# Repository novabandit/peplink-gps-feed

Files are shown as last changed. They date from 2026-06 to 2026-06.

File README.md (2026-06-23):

# Restoring GPS to a Peplink B One 5G (and similar) over raw NMEA

A cheap, reliable way to give a Peplink router a live GPS position again by feeding it raw NMEA 0183 over the LAN. A small ESP32-with-Ethernet board reads a real GPS receiver and pushes the stream to the router. Total parts cost is roughly $40, less if you already own a USB-to-serial adapter.

> **Licenses:** firmware in `firmware/` is MIT (`LICENSE`). The 3D models in `enclosure/`, the documentation in `docs/`, and this README are CC BY-NC-SA 4.0 (`LICENSE-hardware`). The enclosure is a remix of upstream NonCommercial work, so the NonCommercial terms apply to the models and docs; the firmware is original and stays MIT.

## The problem

Some Peplink installs used to get their GPS position from an upstream source (for example a Starlink network GPS feed). When that feed goes away, Peplink InControl no longer shows where the rig is or where it has been. The Peplink B One 5G has **no internal GPS chip**, but it will accept a **raw NMEA 0183 stream over the LAN**. This project is a tiny device that reads a real GPS receiver and pushes that NMEA to the router. It is built and tested on a B One 5G (firmware 8.5.x) and should apply to other Peplink models that expose the same "GPS Receiver for Raw NMEA 0183 Network Stream" feature.

## How it works

```
Roof GPS antenna (active, SMA)
        |
        v
NEO-7M GPS receiver  --UART / NMEA 9600-->  WT32-ETH01 (ESP32 + wired Ethernet)
                                                  |
                                                  |  NMEA over UDP (or TCP)
                                                  v
                                          Peplink LAN port
```

**The #1 conceptual gotcha: who listens and who pushes.**

- The **Peplink is the listener (the server).** It opens a port and waits for a stream to arrive. The "Sender IP" box in its config is an *allowlist of who may push*, not a target it reaches out to.
- The **ESP32 is the client that pushes.** It opens the connection and sends NMEA to the Peplink's LAN IP and port.

Get this backwards and nothing works. This also explains the older "TCP did not work" reports floating around: those used a TCP *server* as the source, which is the wrong role. An ESP acting as a TCP *client* is correct, and UDP is simpler still and is the documented-working case on the B One 5G.

## Bill of materials

Listed by part type. No vendor links on purpose; buy from whoever you trust. Costs are rough, in USD.

| Part type | Role | Approx cost |
|---|---|---|
| **WT32-ETH01** (ESP32 + onboard LAN8720 wired Ethernet) | The brains. Reads the GPS, pushes NMEA over the LAN. | ~$16 |
| **u-blox NEO-7M GPS module** with an SMA jack | The GPS receiver. Outputs NMEA over UART. | ~$11 |
| **Active GPS antenna with SMA** | The real antenna. On an RV this is your roof unit. | varies |
| **12V to 5V buck converter, ~3A** | Powers the stack from the coach 12V. | ~$5 to $13 |
| **Dupont jumper wires (female-to-female)** | Join the boards (both have male pins). | ~$8 kit |
| **USB-to-TTL serial adapter** (FTDI FT232 or similar, with a 3.3V/5V switch) | Flashing the ESP32 and bench-testing the GPS. | ~$8 |
| **Inline fuse holder + ~1A fuse** | Safety on the 12V tap for a permanent install. | ~$5 |
| **Short Ethernet patch cable** | WT32 to the Peplink LAN. | likely on hand |

Notes on choices:

- The **NEO-7M** is plenty for a moving-map feed (GPS + GLONASS, around 2.5 m accuracy). A fancier multi-band receiver buys nothing here, because most RV roof antennas are L1-only. Clear sky and a good antenna matter far more than the chipset.
- **Do not rely on the NEO-7M's onboard ceramic patch antenna.** On many of these boards the RF front end is routed to the **SMA jack**, not the patch, so with nothing on the SMA the module looks deaf (zero or one satellite, no fix) even under open sky. This is a known pattern, corroborated by multiple buyer reviews on the module's listings, not a one-off defect. Plan on using the **SMA with an external active antenna** from the start. On an RV, that external antenna is your roof unit, which is what you want anyway.
- Your **active roof antenna** contains an amplifier and expects a DC **bias voltage** down the coax (commonly 3.3V). Match the GPS module's antenna voltage to your antenna's rating. This build feeds the GPS at 3.3V to keep a 3.3V-bias antenna happy. A worked example: the **Peplink Mobility 42G** is L1-only with a 3.3V bias.

## Tools and software

- A computer with the **Arduino IDE** (free).
- The **ESP32 board package** for Arduino (install steps in `firmware/README.md`).
- A serial terminal for watching NMEA during bring-up (the Arduino Serial Monitor is fine). Note: u-blox u-center is Windows-only, so on macOS or Linux do antenna/config tweaks in firmware rather than in u-center.
- Basic hand tools and a fused 12V source for the final install.

## Wiring

Full detail, pin by pin and stage by stage, is in **`docs/wiring.md`**. In brief:

- There are three wiring stages and you do not need them all at once: **(A)** bench-test the GPS by itself over the FTDI, **(B)** flash the WT32-ETH01 over the FTDI on UART0, **(C)** operation, with the GPS on UART2.
- The GPS talks to the WT32 on **UART2**: GPS **TXD -> IO5** (board silk "RXD"), and optionally GPS **RXD -> IO17** (board silk "TXD"). The IO5 wire is the one that carries data; IO17 is only needed if you want to send config to the GPS.
- Power the GPS from the WT32's **3V3** output pin, not 5V, so an active 3.3V-bias antenna sees its rated voltage.
- During flashing (stage B) you power the board from the **FTDI's VCC into the WT32 3V3 pin**, with the FTDI switch at 3.3V; the Ethernet PHY is idle then, so this is fine. When you switch to operation (stage C) you power the WT32 from the buck's **5V** into the WT32 **5V** pin, and you **remove the FTDI VCC wire**. The PHY is power-hungry and needs a solid, single 5V source, so two supplies on the rail are what to avoid.
- Tap coach 12V through an **inline ~1A fuse** into the buck.

## Firmware and flashing

The sketch lives in **`firmware/`** (`gps_nmea_bridge.ino`), with flashing-specific instructions in **`firmware/README.md`**.

Two things trip people up:

- **The WT32-ETH01 has no USB port and no auto-reset circuit.** You flash it through the FTDI on UART0, and you enter the bootloader by hand: jumper **IO0 -> GND**, click Upload, and when the IDE prints `Connecting....`, **power-cycle the board**. It catches it in download mode. Remove the IO0 jumper and power-cycle again to run.
- **Two different bauds, do not mix them up.** **9600** is the internal GPS-to-ESP link (UART2). **115200** is the USB debug console (the Serial Monitor). Gibberish on the monitor almost always means it is set to the wrong baud.

Power during flashing comes from the FTDI: with the FTDI switch at 3.3V, run **FTDI VCC into the WT32 3V3 pin**. That is fine while flashing because the Ethernet PHY is idle. When you move to operation and feed the buck's 5V into the 5V pin, **remove the FTDI VCC wire** so two supplies are not fighting on the rail. Details are in `firmware/README.md`.

Settings you edit at the top of the sketch: `PEPLINK_IP` (your Peplink's LAN IP), `PEPLINK_PORT`, and `USE_TCP` (0 for UDP, the default; 1 for a TCP client).

## Peplink configuration

Router-side setup is in **`docs/peplink-config.md`**. In brief: **Advanced > "GPS Receiver for Raw NMEA 0183 Network Stream"**, enable it, set **Protocol UDP** and **Port 10110**, and add the ESP's IP to the sender allowlist. Then confirm reception on the router's **Status page**, which has a live GPS map at the bottom that updates **before** InControl does.

## Bring-up and troubleshooting

A walkthrough of the snags worth expecting, and why, is in **`docs/troubleshooting.md`**. The short list: listener-vs-client roles, the SMA-vs-patch antenna trap, the manual bootloader, the **FTDI VCC backfeed that starves the Ethernet PHY and leaves you with no link light** if you leave it connected after switching to 5V, the IO5 strapping pin, antenna bias voltage, and the fact that **InControl lags by minutes, which is normal, so confirm on the Status-page map instead**.

## Enclosure and STLs

Printable STLs are in **`enclosure/`**. The starting point was a small box for the WT32-ETH01 plus the FTDI; the GPS would not fit. The published case is **widened by 30mm along one axis** to open a bay for the NEO-7M next to the existing port wall, so every connector keeps its position.

- Final printable files: `enclosure/Case_wide_30mm_clean.stl` and `enclosure/Lid_wide_30mm.stl`.
- The GPS can be **fully enclosed** with no view of the sky, because it runs off the roof antenna over the SMA, not its onboard patch.
- See `enclosure/README.md` for print orientation, the credit lineage, and a note that these are mesh-only (no parametric CAD source).

## License

- **Firmware** (`firmware/`): MIT, see `LICENSE`.
- **3D models and documentation** (`enclosure/`, `docs/`, this README): Creative Commons Attribution-NonCommercial-ShareAlike 4.0 International (CC BY-NC-SA 4.0), see `LICENSE-hardware`. The enclosure is a remix of upstream NonCommercial work, so these may not be used commercially.

## Credits and sources

- **WT32-ETH01 pinout and Ethernet bring-up**: Werner Rothschopf's excellent WT32-ETH01 reference, which nails the second-UART pins (IO5 / IO17) and the LAN8720 setup. https://werner.rothschopf.net/microcontroller/202401_esp32_wt32_eth01_en.htm
- **The UDP-working case on the B One 5G**: a Peplink community forum thread documenting a working raw-NMEA-over-UDP feed to a B One 5G, which confirmed UDP as the simplest reliable transport and the listener-vs-client roles.
- **Enclosure lineage**: the case is a remix of **Jahara**'s "WT32-ETH01 FT232 Snap Fit Case" on MakerWorld (https://makerworld.com/en/models/1920953-wt32-eth01-ft232-snap-fit-case), which is itself a remix of **Hans** (@Hans_193091)'s "Esp32 WT32-ETH01 USB Type C Snap Fit Case" on Printables (https://www.printables.com/model/770916-esp32-wt32-eth01-usb-type-c-snap-fit-case). Both are licensed CC BY-NC-SA 4.0. See `enclosure/README.md` and `LICENSE-hardware`.
- Built and documented for a motorhome install. Shared in case it saves the next person the same afternoon of debugging.

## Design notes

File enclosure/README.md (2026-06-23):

# Enclosure

3D-printable case and lid for the electronics. License: CC BY-NC-SA 4.0 (see `../LICENSE-hardware`). This is a remix of upstream NonCommercial work, so the NonCommercial terms carry through; see the credit lineage below.

## Printable files

- **`Case_wide_30mm_clean.stl`** — the case.
- **`Lid_wide_30mm.stl`** — the lid.

These are the final, intended files. Print these two.

## What this is

The starting point was a small box sized for the WT32-ETH01 plus an FTDI adapter, with the connector openings on one long wall. That box had **no room for the NEO-7M GPS**. This case is that box **widened by 30mm along the axis the connector wall runs on**, which opens a clean bay at the far end for the GPS while keeping every existing connector opening in its original position. The interior is a single open volume (an internal partition wall from the original design was removed), so you have room to mount the GPS and route the SMA cable.

The GPS can be **fully enclosed** with no opening to the sky, because it runs off the roof antenna over the SMA, not its onboard patch. You only need a cable exit for the SMA pigtail and the power/Ethernet leads.

## Printing

- **Orientation:** print the case open-side up (lid opening facing up) so the walls and connector openings come out clean and the floor is on the bed. The lid prints flat, outer face down. Supports are generally not needed for the case in this orientation.
- These are **mesh-only STLs.** There is **no parametric CAD source**, so edits have to be done at the mesh level (a mesh editor or a boolean/CSG tool), not by tweaking parameters. If you want a different layout, expect to remix the mesh.

## What is intentionally omitted

The original narrower case and the intermediate widened versions are **not included on purpose**, to avoid confusion about which file to print. The two files above supersede all of them. If you specifically want the GPS-less original box for a different build, it is straightforward to print just the WT32 + FTDI footprint, but this repo ships only the final motorhome-GPS enclosure.

## Credits and license lineage

These STLs are a remix, and the whole lineage is licensed **CC BY-NC-SA 4.0** (Attribution, NonCommercial, ShareAlike). The chain:

1. **Original:** Hans (username @Hans_193091), "Esp32 WT32-ETH01 USB Type C Snap Fit Case" on Printables. https://www.printables.com/model/770916-esp32-wt32-eth01-usb-type-c-snap-fit-case
2. **Remix this build started from:** Jahara, "WT32-ETH01 FT232 Snap Fit Case" on MakerWorld. https://makerworld.com/en/models/1920953-wt32-eth01-ft232-snap-fit-case
3. **This version:** Jahara's case widened by 30mm along the connector-wall axis to fit the NEO-7M, with the internal partition wall removed.

Because the upstream work is **NonCommercial**, these models and the documentation that ships with them may not be used commercially. Because it is **ShareAlike**, any further remix must carry the same CC BY-NC-SA 4.0 license and preserve this attribution chain. License text: https://creativecommons.org/licenses/by-nc-sa/4.0/

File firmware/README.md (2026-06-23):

# Firmware: GPS NMEA bridge for WT32-ETH01

The sketch `gps_nmea_bridge.ino` reads NMEA 0183 from a NEO-7M GPS on UART2 at 9600 baud and pushes each sentence over the wired LAN to a Peplink listening as the "GPS Receiver for Raw NMEA 0183 Network Stream." Transport defaults to UDP; a one-line change makes it a TCP client.

License: MIT (see `../LICENSE`).

## Toolchain

1. Install the **Arduino IDE**.
2. Add the ESP32 board package. In **Settings > Additional boards manager URLs**, add:
   `https://espressif.github.io/arduino-esp32/package_esp32_index.json`
3. In **Boards Manager**, install **"esp32 by Espressif Systems."**
4. Select the board **"WT32-ETH01 Ethernet Module"** if it is in your list, or **"ESP32 Dev Module"** otherwise.

The sketch compiles on both ESP32 Arduino core 2.x and 3.x; the `ETH.begin` call is branched on the core version, so you do not need a specific core.

## Settings to edit

At the top of the sketch, set:

- `PEPLINK_IP` — your Peplink's LAN IP, the listener. The example is `192.168.50.1` (the Peplink default); set it to your Peplink's actual LAN IP.
- `PEPLINK_PORT` — must match the port you set on the Peplink. The example is `10110`, the registered NMEA-0183-over-IP port.
- `USE_TCP` — `0` for UDP (the default and the documented-working transport), or `1` for a TCP client with auto-reconnect.

The GPS pin and baud defines (`GPS_RX_PIN 5`, `GPS_TX_PIN 17`, `GPS_BAUD 9600`) and the LAN8720 Ethernet defines are correct for the WT32-ETH01 and should be left as-is.

## FTDI wiring for flashing (power from FTDI VCC, remove it for operation)

Flash through the FTDI on UART0 with the **FTDI switch set to 3.3V**:

| FTDI | -> | WT32-ETH01 |
|---|---|---|
| VCC | -> | 3V3  (powers the board for flashing) |
| GND | -> | GND |
| TXD | -> | RX0  (silk "RXO") |
| RXD | -> | TX0  (silk "TXO") |

Plus the bootloader jumper **IO0 -> GND**.

> **Power from the FTDI to flash, then disconnect FTDI VCC when you switch to 5V for operation.** With the FTDI switch at 3.3V, feed **FTDI VCC into the WT32 3V3 pin** to power the board while flashing. This works because the Ethernet PHY is idle during the flash. When you move to operation and power the board from the buck's **5V** on the **5V** pin, **remove the FTDI VCC wire** (keep GND/TX/RX if you still want the serial console). Leaving FTDI VCC connected alongside the 5V supply backfeeds and sags the rail, which starves the power-hungry Ethernet PHY so the link never comes up. See `../docs/troubleshooting.md`.
>
> Also **disconnect the GPS while flashing** (IO5 is a strapping pin).

## Manual bootloader steps

The WT32-ETH01 has no USB and no auto-reset, so you enter the bootloader by hand:

1. With **IO0 jumpered to GND**, click **Upload** in the Arduino IDE.
2. When the IDE prints `Connecting....`, **power-cycle the board**. It catches the chip in download mode and flashes.
3. When it finishes, **remove the IO0 jumper** and power-cycle again to run.

## Bench validation

Open the **Serial Monitor at 115200 baud**. You should see:

- the startup banner,
- a `[status]` heartbeat line every 5 seconds (so the console shows life even before a GPS fix or an Ethernet link exists),
- once the GPS is wired (UART2) and talking, `$GP...` sentences scrolling and the "sentences forwarded" counter climbing,
- once the Ethernet is plugged into any DHCP LAN, the status line flipping to `link up` with an IP, and a one-time line printing the board's **IP and MAC**.

The firmware prints **your board's MAC** at boot once it has a link; use that value if you want to set a DHCP reservation on the router. (Do not copy a MAC from anyone else's writeup; it is unique to each board.)

If the Serial Monitor shows gibberish, it is set to the wrong baud. The GPS link is 9600; the console is 115200. Do not mix them up.

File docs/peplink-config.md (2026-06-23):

# Peplink configuration

Tested on a Peplink B One 5G running firmware 8.5.x. Other Peplink models that expose the same feature should behave the same way.

## Enable the NMEA stream listener

Open the router's web admin and go to:

**Advanced > "GPS Receiver for Raw NMEA 0183 Network Stream"**

Enable it and set:

- **Protocol: UDP.** This matches the firmware default and is the documented-working transport on the B One 5G. TCP also works if you set `USE_TCP 1` in the firmware and reflash; in that case the ESP connects as a TCP *client*. Do not configure the Peplink as a TCP client pulling from the ESP, the router is always the listener.
- **Port: 10110.** This is the registered NMEA-0183-over-IP port and is a sensible public default. It must match `PEPLINK_PORT` in the firmware. Any free port works as long as both sides agree.
- **Access Control / Sender IP allowlist:** allow the ESP's IP to push to the router. Two approaches both work:
  - **Single host (/32):** reserve a DHCP address for the ESP (by its MAC) and allowlist exactly that one IP. Tightest, but you have to set up the reservation.
  - **Subnet (/24):** allowlist `<ESP_IP> / 255.255.255.0`, which tolerates the ESP's IP drifting anywhere inside `192.168.50.0/24`. This is what this build used in practice, and it means a DHCP reservation is optional.

The firmware prints the board's IP and MAC on the USB serial console at boot, so you have the values you need for either approach. Use **your** Peplink's LAN IP for `PEPLINK_IP` in the firmware (the examples here use `192.168.50.1`, the Peplink default).

## What the router wants

The router is happy with **RMC and GGA** (together they cover position, time, fix quality and satellite count). The firmware forwards every NMEA sentence the GPS emits, which is harmless; the router simply ignores what it does not use.

## Confirming reception

There are two readouts, and they update at very different speeds:

- **The Status-page GPS map (fast).** On the B One 5G, the main **Status** page has a **live GPS location map at the bottom**. Scroll down to find it. This map reflects the incoming fix within seconds of a good stream arriving, and it updates **before** InControl does. This is the right place to confirm the router is receiving your feed.
- **InControl (slow).** InControl shows the same position eventually, but it lags by minutes because of normal cloud reporting intervals. Do not stand at the rig waiting on InControl to decide whether the build works. Watch the Status-page map.

The Peplink **Event Log** records the LAN port coming up (for example "Port link up, 100 Mbps full duplex") but does **not** log NMEA stream content, so the Event Log confirms the cable and link, not the feed. Use the Status-page map for the feed itself.

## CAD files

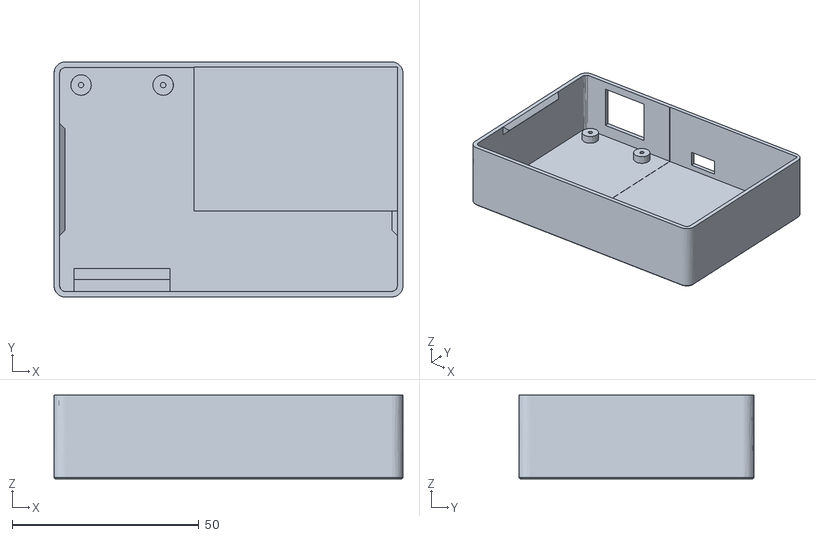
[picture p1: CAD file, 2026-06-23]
enclosure/Case_wide_30mm_clean.stl
93.5 x 63.0 x 22.5

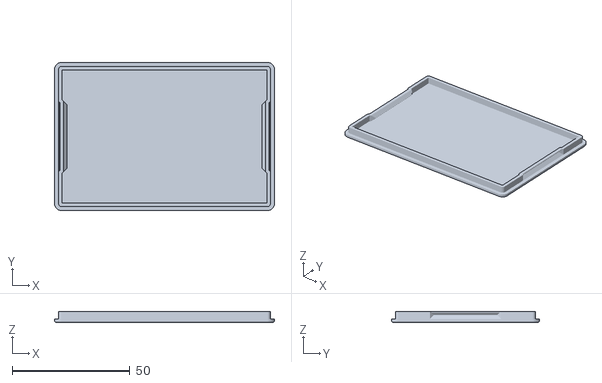
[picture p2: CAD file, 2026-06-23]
enclosure/Lid_wide_30mm.stl
93.5 x 63.0 x 4.50

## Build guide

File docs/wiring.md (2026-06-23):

# Wiring

There are three wiring stages. You do not need them all wired at once: stage A proves the GPS, stage B flashes the ESP32, stage C is the running configuration. The same FTDI adapter is reused across A and B.

> Throughout, set the **FTDI's 3.3V/5V switch to 3.3V**. The ESP32 and the GPS are 3.3V-logic parts.

## Pin references

**NEO-7M GPS header** (left to right):

```
VCC   GND   TXD   RXD   PPS
```

**FTDI FT232 header** (order varies by board, match by silk label). The pins you use:

```
... RXD   TXD   GND   VCC
```

Plus a **3.3V/5V slide switch** (use 3.3V).

**WT32-ETH01**, the pins this build touches:

- **UART0** (flashing and the USB debug console): `TX0` (silk "TXO"), `RX0` (silk "RXO")
- **UART2** (the GPS data link): `IO5` (silk "RXD"), `IO17` (silk "TXD")
- Power and control: `5V`, `3V3` (regulator output), `GND`, `IO0` (hold low to enter flash mode)

The IO5 / IO17 mapping for the right-side `RXD` / `TXD` header is from the Werner Rothschopf WT32-ETH01 reference. Those two pins also drive small active-low green LEDs on the board, which is harmless and gives you a handy data-activity blink.

## Stage A (optional): bench-test the GPS by itself

This proves the GPS module works before you involve the ESP32. **Set the FTDI switch to 3.3V.**

| FTDI | -> | NEO-7M |
|---|---|---|
| VCC | -> | VCC |
| GND | -> | GND |
| RXD | -> | TXD  (GPS talks, FTDI listens) |
| TXD | -> | RXD  (optional, only needed to send config) |

Leave **PPS** open. TX/RX cross over: the GPS's TXD goes to the FTDI's RXD.

Put an **active antenna on the SMA jack** (see the antenna note below), plug the FTDI into the computer, and open a serial terminal at **9600 baud**. You will see `$GPRMC,...` and friends. With no fix the RMC carries a `V` (void) with empty coordinates; once it locks, the status flips to `A` (active) with real latitude and longitude, and `$GPGGA` shows a rising satellite count.

> **Antenna, important:** do not trust the onboard ceramic patch. On many NEO-7M boards the RF is routed to the **SMA**, not the patch, so the module looks dead with nothing on the SMA even under open sky. This is a known pattern across these boards, not a one-off. Use an external active antenna on the SMA. See `troubleshooting.md` for the full story.

## Stage B: flash the WT32-ETH01

The WT32-ETH01 has **no USB port**, so you flash it through the FTDI on UART0. **Disconnect the GPS for this step** (IO5 is a strapping pin, see troubleshooting). **Set the FTDI switch to 3.3V.**

| FTDI | -> | WT32-ETH01 |
|---|---|---|
| VCC | -> | 3V3  (powers the board for flashing) |
| GND | -> | GND |
| TXD | -> | RX0  (silk "RXO") |
| RXD | -> | TX0  (silk "TXO") |

Plus a jumper: **IO0 -> GND** (this is what selects flash mode). TX and RX cross over.

> **Power the board from the FTDI to flash, then disconnect FTDI VCC when you switch to 5V for operation.** With the FTDI switch at 3.3V, feed **FTDI VCC into the WT32 3V3 pin** to power the board for flashing. This is fine because the Ethernet PHY is idle while flashing, so the modest current the FTDI supplies is enough. The critical step is the transition to operation: when you move to stage C and power the board from the buck's **5V** into the **5V** pin, you must **remove the FTDI VCC wire** (keep GND/TX/RX if you still want the serial console). Leaving FTDI VCC connected puts two supplies on the rail, the FTDI's 3.3V and the buck's 5V through the onboard regulator, and they backfeed and sag it. The power-hungry LAN8720 PHY is then starved and the Ethernet link never comes up. That is the classic "everything flashes fine but the link light never comes on" failure. See `troubleshooting.md`.

For the manual-bootloader keystrokes, see `../firmware/README.md`.

## Stage C: operation, GPS to WT32

After flashing, remove the IO0 jumper, remove the **FTDI VCC wire**, and wire the GPS to UART2.

| NEO-7M | -> | WT32-ETH01 |
|---|---|---|
| VCC | -> | 3V3  (powers the GPS at 3.3V) |
| GND | -> | GND |
| TXD | -> | IO5  (silk "RXD")  <- the data wire that matters |
| RXD | -> | IO17 (silk "TXD")  (optional, config only) |

Leave **PPS** open. TX and RX cross over here too: the GPS's TXD goes to IO5.

Power the WT32 from the buck's **5V** into the WT32 **5V** pin, with the FTDI VCC wire removed so only one supply feeds the rail. Power the GPS from the WT32's **3V3** output pin, not 5V. That keeps an active 3.3V-bias antenna at its rated voltage. The chain is: **5V in -> WT32 -> 3V3 out -> GPS.** If you keep the FTDI attached for the serial console, leave only GND/TX/RX connected, never VCC.

## Final install power

```
Coach 12V  --(inline ~1A fuse)-->  buck converter  --5V-->  WT32-ETH01 (5V pin)
                                                            WT32 3V3 out  -->  GPS VCC
                                                            WT32 Ethernet -->  Peplink LAN port
Roof antenna (SMA male)  -->  GPS SMA jack
```

- The **fuse** protects the harness against a 12V short; size it small (around 1A) since the whole stack draws very little.
- Unscrew any bundled ceramic puck from the GPS SMA jack and connect the **roof antenna** there.
- Because the GPS runs entirely off the roof antenna, the electronics can live anywhere convenient and be fully enclosed; they need no view of the sky.

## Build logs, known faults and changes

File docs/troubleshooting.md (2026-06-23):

# Troubleshooting and gotchas

These are the snags worth expecting on this build, with the reason behind each. Most of them are easy once you know to expect them.

## 1. Listener vs client (the conceptual one)

The **Peplink is the listener (server)**: it opens the port and waits. The **ESP is the client that pushes** the stream to the router's LAN IP and port. The "Sender IP" field on the router is an *allowlist of who may push*, not a target it pulls from.

This is the root of the old "TCP did not work on the B One" reports: those setups used a TCP *server* as the GPS source, which is the wrong role for this feature. An ESP acting as a TCP *client* is correct. UDP is simpler still and is the documented-working case, so start there.

## 2. The onboard patch antenna looks dead (SMA vs patch)

Symptom: under open sky, the NEO-7M sees zero satellites, or one satellite intermittently, and never gets a fix, even after 15 minutes outdoors away from the laptop.

Cause: on many of these NEO-7M boards the RF front end is routed to the **SMA jack, not the onboard ceramic patch**. With nothing on the SMA the receiver is effectively antenna-less, and any momentary single-satellite blips are stray coupling, not real reception. This is a **known issue with these boards**, corroborated by multiple buyer reviews on the module's listings, not a defect unique to one unit.

Fix: **do not rely on the onboard patch. Use the SMA with an external active antenna.** On an RV that external antenna is your roof unit, which is what you want anyway. If you ever need to confirm the routing on the bench, put a known-good active antenna on the SMA and you should fix within a minute or two of clear sky.

## 3. No USB and no auto-reset (manual bootloader)

The WT32-ETH01 has **no USB port** and **no auto-reset circuit**, so you cannot just click Upload and walk away. Flash it through the FTDI on UART0 and enter the bootloader by hand:

1. Jumper **IO0 -> GND**.
2. In the Arduino IDE, click **Upload**.
3. When the IDE prints `Connecting....`, **power-cycle the board** (pull and restore its power). It catches the chip in download mode and flashes.
4. When the flash finishes, **remove the IO0 jumper** and power-cycle again to run normally.

## 4. FTDI VCC left connected during operation backfeeds the rail (the nasty one)

Symptom: the board flashes perfectly, the firmware runs, the serial console looks healthy, but the **Ethernet link light never comes on** and you never get a DHCP IP.

Cause: during flashing it is correct to power the board from the **FTDI's VCC into the 3V3 pin** (the Ethernet PHY is idle then, so the FTDI supplies enough current). The trouble starts at the transition to operation. When you bring in the buck's **5V** on the 5V pin but leave the **FTDI VCC wire still connected**, two supplies share the rail: the FTDI's 3.3V and the buck's 5V through the onboard regulator. They backfeed and **sag the rail**. The LAN8720 Ethernet PHY is power-hungry, and on that sagging rail it never comes up, so you get no link.

Fix: when you switch to 5V for operation, **remove the FTDI VCC wire** (keep GND/TX/RX if you want the serial console) and power the board from a solid **5V** source (the buck, or a USB charger) into the WT32's **5V** pin. With FTDI VCC removed and clean 5V in, the board pulls DHCP immediately and the Peplink logs the port link-up at 100 Mbps full duplex.

The rule is "power from the FTDI to flash, then disconnect FTDI VCC when you switch to 5V for operation," not "never connect FTDI VCC." This is the single most common "it all works except Ethernet" failure on this board. If your link light is dark after you have moved to 5V, check this first.

## 5. IO5 is a strapping pin

GPIO5 (the GPS data line, board silk "RXD") is an ESP32 **boot-strapping pin**. If the GPS is connected and driving that line while the board powers up to flash, it can interfere with entering the bootloader. **Disconnect the GPS while flashing** (stage B), and only wire it to UART2 afterward (stage C). As a bonus, IO5 and IO17 drive small onboard green LEDs, so once the GPS is connected and talking you get a free data-activity blink.

## 6. Match the antenna bias voltage (3.3V)

An active GPS antenna contains an amplifier fed DC **bias voltage** down the coax, and it has a rated voltage (commonly **3.3V**). Power the GPS module from the WT32's **3V3** output pin, not 5V, so the bias the module puts on the SMA matches the antenna's rating. For example, the Peplink Mobility 42G is a 3.3V-bias, L1-only antenna, so 3.3V is correct for it. Feeding 5V to a 3.3V antenna is the kind of thing that works for a while and then does not.

## 7. InControl lags, watch the Status-page map instead

Symptom: the build is running, the router clearly has a fix, but **InControl is not updating**.

This is almost always **normal reporting lag**, not a fault. InControl updates on a cloud reporting interval and can trail the live position by minutes.

Fix: confirm reception on the router's own **Status page**, which has a **live GPS map at the bottom** that updates within seconds and **ahead of InControl**. If the Status-page map shows your position, the feed is working; InControl will catch up on its own schedule. (Note the Event Log shows only the LAN port link-up, not the NMEA content, so it is not the place to confirm the feed.)

## 8. Two bauds, do not mix them up

**9600** is the internal GPS-to-ESP link on UART2. **115200** is the USB debug console (the Serial Monitor). If the Serial Monitor shows gibberish, it is almost always set to the wrong baud; set it to 115200.

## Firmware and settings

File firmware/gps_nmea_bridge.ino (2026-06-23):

/*
 * Motorhome GPS NMEA bridge  -  WT32-ETH01 (ESP32 + LAN8720 wired Ethernet)
 *
 * Reads NMEA 0183 from a NEO-7M GPS on UART2 at 9600 baud and pushes each
 * sentence over the wired LAN to the Peplink B One 5G, which listens as the
 * "GPS Receiver for Raw NMEA 0183 Network Stream".
 *
 * Transport defaults to UDP (the one documented-working B One 5G case used UDP).
 * Set USE_TCP to 1 to send as a TCP client instead (auto-reconnects on drop).
 *
 * Arduino IDE + ESP32 board support. Compiles on core 2.x and 3.x (the
 * ETH.begin call is branched on version). Board: "WT32-ETH01 Ethernet Module",
 * or "ESP32 Dev Module" if that entry is not in your list.
 */

#include <Arduino.h>
#include <ETH.h>
#include <WiFiUdp.h>
#include <WiFiClient.h>

// ---------- user settings ----------
#define USE_TCP        0              // 0 = UDP (default), 1 = TCP client
#define PEPLINK_IP     "192.168.50.1" // your Peplink LAN IP (the listener); 192.168.50.1 is the Peplink default
#define PEPLINK_PORT   10110          // matches the Peplink NMEA stream port

// GPS on UART2. Pins are the WT32-ETH01 right-side header:
//   board silk "RXD" = GPIO5  -> ESP receive  (wire GPS TXD here, the one that matters)
//   board silk "TXD" = GPIO17 -> ESP transmit (wire GPS RXD here, optional, config only)
#define GPS_RX_PIN     5
#define GPS_TX_PIN     17
#define GPS_BAUD       9600
// ------------------------------------

// WT32-ETH01 LAN8720 wiring (leave as-is for this board)
#define ETH_PHY        ETH_PHY_LAN8720
#define ETH_ADDR       1
#define ETH_POWER_PIN  16
#define ETH_MDC_PIN    23
#define ETH_MDIO_PIN   18
#define ETH_CLK        ETH_CLOCK_GPIO0_IN

WiFiUDP    udp;
WiFiClient tcp;
unsigned long lastTcpTry = 0;
unsigned long lastStatus = 0;
unsigned long sentCount  = 0;

char line[128];
int  lineLen = 0;

void forwardSentence(const char *buf, int len) {
#if USE_TCP
  if (!tcp.connected()) {
    if (millis() - lastTcpTry > 2000) {
      lastTcpTry = millis();
      tcp.connect(PEPLINK_IP, PEPLINK_PORT);
    }
    if (!tcp.connected()) return;          // still down, drop this sentence
  }
  tcp.write((const uint8_t *)buf, len);
#else
  udp.beginPacket(PEPLINK_IP, PEPLINK_PORT);
  udp.write((const uint8_t *)buf, len);
  udp.endPacket();
#endif
  sentCount++;
  Serial.write((const uint8_t *)buf, len);  // echo to USB serial for bench debug
}

void setup() {
  Serial.begin(115200);
  delay(300);
  Serial.println();
  Serial.println("Motorhome GPS NMEA bridge starting");

  Serial2.begin(GPS_BAUD, SERIAL_8N1, GPS_RX_PIN, GPS_TX_PIN);

#if ESP_ARDUINO_VERSION_MAJOR >= 3
  ETH.begin(ETH_PHY, ETH_ADDR, ETH_MDC_PIN, ETH_MDIO_PIN, ETH_POWER_PIN, ETH_CLK);
#else
  ETH.begin(ETH_ADDR, ETH_POWER_PIN, ETH_MDC_PIN, ETH_MDIO_PIN, ETH_PHY, ETH_CLK);
#endif

  Serial.print("Bringing up Ethernet (DHCP)");
  unsigned long t0 = millis();
  while ((uint32_t)ETH.localIP() == 0 && millis() - t0 < 20000) {
    Serial.print('.');
    delay(500);
  }
  Serial.println();

  if ((uint32_t)ETH.localIP() == 0) {
    Serial.println("No IP yet. Check cable/link; it will keep retrying below.");
  } else {
    Serial.print("Link up. IP ");
    Serial.print(ETH.localIP());
    Serial.print("  MAC ");
    Serial.println(ETH.macAddress());
    Serial.print("Reserve this MAC on the Peplink, whitelist its IP. Sending to ");
    Serial.print(PEPLINK_IP); Serial.print(':'); Serial.print(PEPLINK_PORT);
    Serial.println(USE_TCP ? " over TCP" : " over UDP");
  }
}

void loop() {
  // pull NMEA from the GPS one line at a time, forward complete sentences
  while (Serial2.available()) {
    char c = Serial2.read();
    if (lineLen < (int)sizeof(line) - 1) {
      line[lineLen++] = c;
    } else {
      lineLen = 0;                    // overflow guard, drop the runt
    }
    if (c == '\n') {
      line[lineLen] = '\0';
      if (line[0] == '$') {           // forward valid NMEA only
        forwardSentence(line, lineLen);
      }
      lineLen = 0;
    }
  }

  // heartbeat every 5s so the bench shows life even before a fix exists
  if (millis() - lastStatus > 5000) {
    lastStatus = millis();
    Serial.print("[status] ip ");
    Serial.print(ETH.localIP());
    Serial.print("  link ");
    Serial.print(ETH.linkUp() ? "up" : "down");
    Serial.print("  sentences forwarded ");
    Serial.println(sentCount);
  }
}

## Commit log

2026-06-23 initial: peplink gps feed build guide, firmware, and enclosure STLs
    [Case_wide_30mm_clean.stl, Lid_wide_30mm.stl]
2026-06-23 fix stage B flashing power (power from FTDI, remove VCC at operation); neutralize voice; relicense enclosure CC BY-NC-SA 4.0 with Hans/Jahara attribution
